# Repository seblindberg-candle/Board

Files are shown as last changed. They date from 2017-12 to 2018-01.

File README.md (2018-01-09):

# Candle Board

The EAGLE Cad board files for the Candle project can be found here.

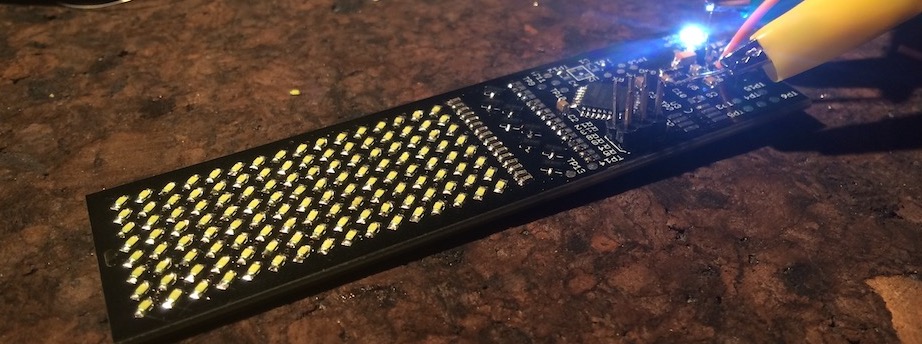
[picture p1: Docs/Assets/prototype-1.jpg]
Prototype 1


## TODO

- [x] Add a pull-up on the flash memory chip select line.
- [x] Fix the MOSFET orientation.
- [x] Fix the flash memory footprint.
- [x] Remove the hole.
- [x] Remove the microphone
- [ ] Switch out the power supply.
- [ ] Move the status LEDs to the back.
- [ ] Move the button to a more reachable position
- [ ] Make the serial port easier to connect to
- [ ] Increase the board length to 25-30 cm
- [x] Bias the display driver current sense line with the DAC
- [ ] Add one or two light sensors (front and/or back)

The following hardware changes are based on features/limitations in the peripherals that where not discovered until after the first revision.

- [ ] Connect the flash memory to `SPIC`
- [ ] Connect the display driver to `USARTD0`
- [ ] Connect `DISP_LE` to an event output (`PC4`, `PC7`, `PD4` or `PD7`)
- [ ] Connect `DISP_OE` to a compare output (`PD2`, since it is unused)
- [ ] Connect the board serial port to `USARTC0`

## Revisions

Board revisions are kept as tags in git. The board is generally tagged when the files have been sent off for manufacturing. To export a specific revision, simply run

```
$ git archive --format zip -o /path/to/rev-a.zip 4d268f
```

where the hash of the tag can be found by running `git show rev-a` for the specific tag.

## Notes

### MOSFET Pull-ups

The pull-ups are required because of the internal protection diods in the main IC. They will not allow the voltage to exceed ~3.8 V. The resistors connected to the gates thus serve to:

1. protect the gate from inrush current,
2. pull the gate high on startup and
3. set the voltage at the gate to a value above the turn-on threshold.

## Scripts

Some ruby scripts are included for generating EAGLE commands that place some of the more repetitive components. There are tools in EAGLE for achieving the same thing and they are most likely better, but a) I did not know that at the time and b) the scripts allowed be to also remove the labels, which would otherwise have been quite a task in itself. 

To run the scripts you need to locate the Scripts folder in your terminal of choice and type `ruby place-diods.rb`. Then press `enter` and copy the output into the command input in EAGLE.

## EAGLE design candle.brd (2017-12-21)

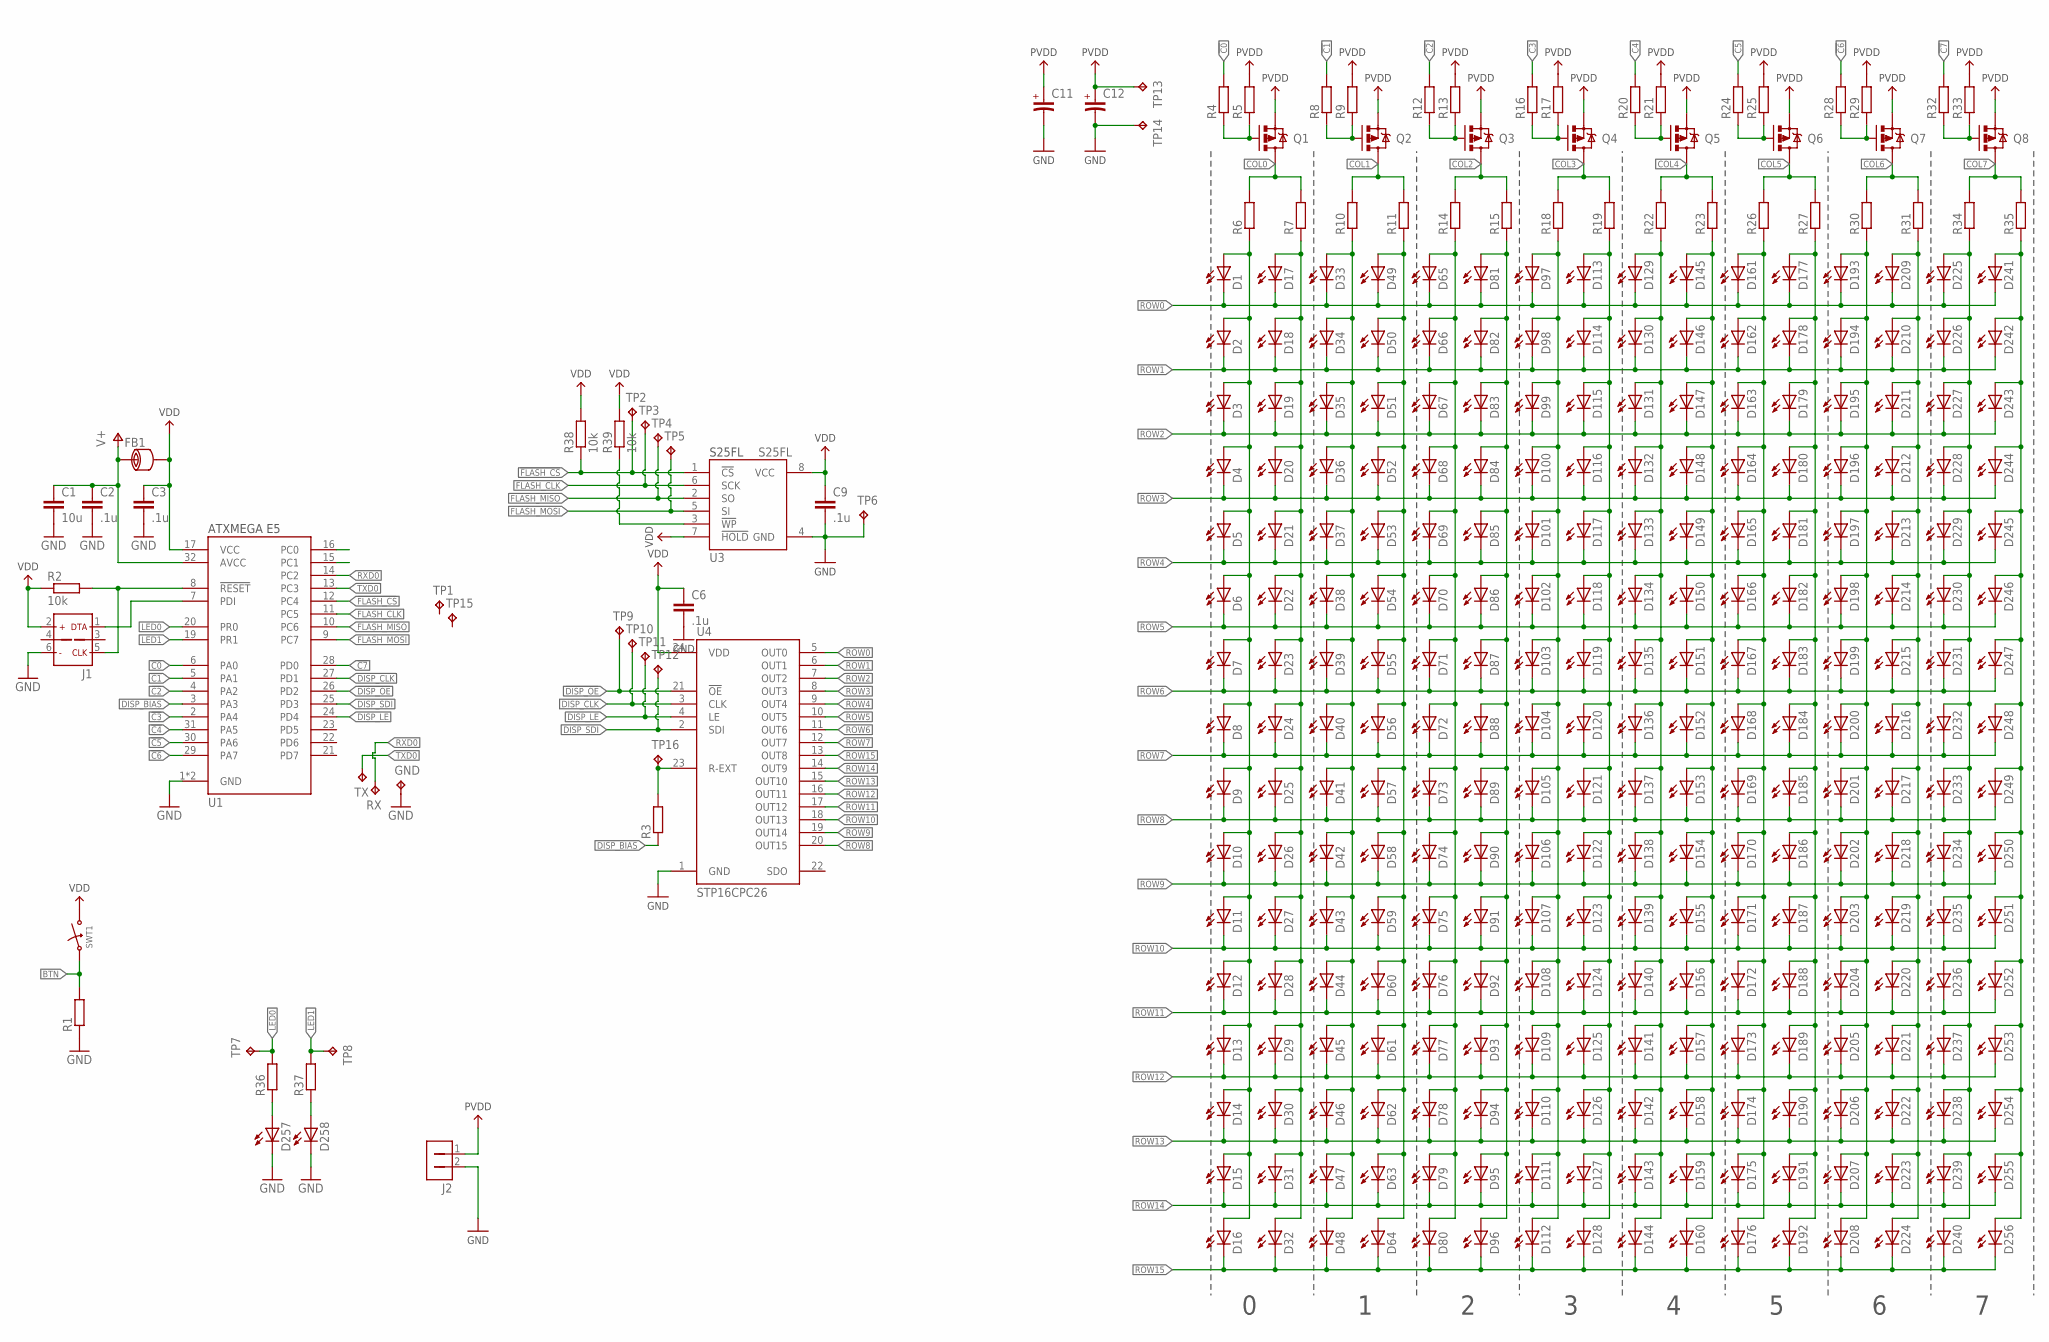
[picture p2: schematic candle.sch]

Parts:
C1: 10u; 0805
C2, C3, C6, C9: .1u; 0805
C11, C12: C_POL_1206; 1206_POL
D1, D2, D3, D4, D5, D6, D7, D8, D9, D10, D11, D12, D13, D14, D15, D16, D17, D18, D19, D20, D21, D22, D23, D24, D25, D26, D27, D28, D29, D30, D31, D32, D33, D34, D35, D36, D37, D38, D39, D40, D41, D42, D43, D44, D45, D46, D47, D48, D49, D50, D51, D52, D53, D54, D55, D56, D57, D58, D59, D60, D61, D62, D63, D64, D65, D66, D67, D68, D69, D70, D71, D72, D73, D74, D75, D76, D77, D78, D79, D80, D81, D82, D83, D84, D85, D86, D87, D88, D89, D90, D91, D92, D93, D94, D95, D96, D97, D98, D99, D100, D101, D102, D103, D104, D105, D106, D107, D108, D109, D110, D111, D112, D113, D114, D115, D116, D117, D118, D119, D120, D121, D122, D123, D124, D125, D126, D127, D128, D129, D130, D131, D132, D133, D134, D135, D136, D137, D138, D139, D140, D141, D142, D143, D144, D145, D146, D147, D148, D149, D150, D151, D152, D153, D154, D155, D156, D157, D158, D159, D160, D161, D162, D163, D164, D165, D166, D167, D168, D169, D170, D171, D172, D173, D174, D175, D176, D177, D178, D179, D180, D181, D182, D183, D184, D185, D186, D187, D188, D189, D190, D191, D192, D193, D194, D195, D196, D197, D198, D199, D200, D201, D202, D203, D204, D205, D206, D207, D208, D209, D210, D211, D212, D213, D214, D215, D216, D217, D218, D219, D220, D221, D222, D223, D224, D225, D226, D227, D228, D229, D230, D231, D232, D233, D234, D235, D236, D237, D238, D239, D240, D241, D242, D243, D244, D245, D246, D247, D248, D249, D250, D251, D252, D253, D254, D255, D256, D257, D258: LED_0805; 0805_LED
FB1: FB_0603; 0603
GND: TPB1,27; B1,27
J1: PDI_LOCK; 2X3_LOCK
J2: 1X2_MOLEX_53254
Q1, Q2, Q3, Q4, Q5, Q6, Q7, Q8: PMV160UP; SOT23
R1, R3, R4, R5, R6, R7, R8, R9, R10, R11, R12, R13, R14, R15, R16, R17, R18, R19, R20, R21, R22, R23, R24, R25, R26, R27, R28, R29, R30, R31, R32, R33, R34, R35, R36, R37: R_0603; 0603
R2: 10k; 0805
R38, R39: 10k; 0603
RX: TPB1,27; B1,27
SWT1: BUTTON_SMD_2P; BTN_SMD_2PIN
TP1, TP2, TP3, TP4, TP5, TP6, TP7, TP8, TP9, TP10, TP11, TP12, TP13, TP14, TP15, TP16: TPB1,27; B1,27
TX: TPB1,27; B1,27
U1: ATXMEGA_E5_TQFP; TQFP32
U3: S25FL; SO8
U4: STP16CPC26TSSOP24; TSSOP24

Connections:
!C0: R4.2, U1.6 (PA0)
!C0_: Q1.1 (G), R4.1, R5.1
!C1: R8.2, U1.5 (PA1)
!C2: R12.2, U1.4 (PA2)
!C3: R16.2, U1.2 (PA4)
!C3_: Q4.1 (G), R16.1, R17.1
!C4: R20.2, U1.31 (PA5)
!C5: R24.2, U1.30 (PA6)
!C5_: Q6.1 (G), R24.1, R25.1
!C6: R28.2, U1.29 (PA7)
!C6_: Q7.1 (G), R28.1, R29.1
!C7: R32.2, U1.28 (PD0)
!C7_: Q8.1 (G), R32.1, R33.1
!DISP_OE: TP9.TP, U1.26 (PD2), U4.21 (!OE)
!FLASH_CS: R38.1, TP2.TP, U1.12 (PC4), U3.1 (!CS)
!RESET: J1.5 (CLK), R2.2, U1.8 (!RESET)
BTN: R1.2, SWT1.1
COL0: Q1.3 (D), R6.2, R7.2
COL1: Q2.3 (D), R10.2, R11.2
COL2: Q3.3 (D), R14.2, R15.2
COL3: Q4.3 (D), R18.2, R19.2
COL4: Q5.3 (D), R22.2, R23.2
COL5: Q6.3 (D), R26.2, R27.2
COL6: Q7.3 (D), R30.2, R31.2
COL7: Q8.3 (D), R34.2, R35.2
DISP_BIAS: R3.1, U1.3 (PA3)
DISP_CLK: TP10.TP, U1.27 (PD1), U4.3 (CLK)
DISP_LE: TP11.TP, U1.24 (PD4), U4.4 (LE)
DISP_SDI: TP12.TP, U1.25 (PD3), U4.2 (SDI)
FLASH_CLK: TP3.TP, U1.11 (PC5), U3.6 (SCK)
FLASH_MISO: TP4.TP, U1.10 (PC6), U3.2 (SO)
FLASH_MOSI: TP5.TP, U1.9 (PC7), U3.5 (SI)
GND: C1.2, C2.2, C3.2, C6.2, C9.2, C11.2, C12.2, D257.C, D258.C, GND.TP, J1.6 (GND), J2.2, R1.1, TP6.TP, TP14.TP, U1.1 (GND), U1.18 (GND), U3.4 (GND), U4.1 (GND)
LED0: R36.2, TP7.TP, U1.20 (PR0)
LED1: R37.2, TP8.TP, U1.19 (PR1)
unnamed: D257.A, R36.1
unnamed: D1.A, D2.A, D3.A, D4.A, D5.A, D6.A, D7.A, D8.A, D9.A, D10.A, D11.A, D12.A, D13.A, D14.A, D15.A, D16.A, R6.1
unnamed: D17.A, D18.A, D19.A, D20.A, D21.A, D22.A, D23.A, D24.A, D25.A, D26.A, D27.A, D28.A, D29.A, D30.A, D31.A, D32.A, R7.1
unnamed: D258.A, R37.1
unnamed: R39.1, U3.3 (!WP)
unnamed: Q2.1 (G), R8.1, R9.1
unnamed: D65.A, D66.A, D67.A, D68.A, D69.A, D70.A, D71.A, D72.A, D73.A, D74.A, D75.A, D76.A, D77.A, D78.A, D79.A, D80.A, R14.1
unnamed: D81.A, D82.A, D83.A, D84.A, D85.A, D86.A, D87.A, D88.A, D89.A, D90.A, D91.A, D92.A, D93.A, D94.A, D95.A, D96.A, R15.1
unnamed: R3.2, TP16.TP, U4.23 (R-EXT)
unnamed: D129.A, D130.A, D131.A, D132.A, D133.A, D134.A, D135.A, D136.A, D137.A, D138.A, D139.A, D140.A, D141.A, D142.A, D143.A, D144.A, R22.1
unnamed: D145.A, D146.A, D147.A, D148.A, D149.A, D150.A, D151.A, D152.A, D153.A, D154.A, D155.A, D156.A, D157.A, D158.A, D159.A, D160.A, R23.1
unnamed: Q3.1 (G), R12.1, R13.1
unnamed: Q5.1 (G), R20.1, R21.1
unnamed: D97.A, D98.A, D99.A, D100.A, D101.A, D102.A, D103.A, D104.A, D105.A, D106.A, D107.A, D108.A, D109.A, D110.A, D111.A, D112.A, R18.1
unnamed: D113.A, D114.A, D115.A, D116.A, D117.A, D118.A, D119.A, D120.A, D121.A, D122.A, D123.A, D124.A, D125.A, D126.A, D127.A, D128.A, R19.1
unnamed: D161.A, D162.A, D163.A, D164.A, D165.A, D166.A, D167.A, D168.A, D169.A, D170.A, D171.A, D172.A, D173.A, D174.A, D175.A, D176.A, R26.1
unnamed: D177.A, D178.A, D179.A, D180.A, D181.A, D182.A, D183.A, D184.A, D185.A, D186.A, D187.A, D188.A, D189.A, D190.A, D191.A, D192.A, R27.1
unnamed: D193.A, D194.A, D195.A, D196.A, D197.A, D198.A, D199.A, D200.A, D201.A, D202.A, D203.A, D204.A, D205.A, D206.A, D207.A, D208.A, R30.1
unnamed: D209.A, D210.A, D211.A, D212.A, D213.A, D214.A, D215.A, D216.A, D217.A, D218.A, D219.A, D220.A, D221.A, D222.A, D223.A, D224.A, R31.1
unnamed: D225.A, D226.A, D227.A, D228.A, D229.A, D230.A, D231.A, D232.A, D233.A, D234.A, D235.A, D236.A, D237.A, D238.A, D239.A, D240.A, R34.1
unnamed: D241.A, D242.A, D243.A, D244.A, D245.A, D246.A, D247.A, D248.A, D249.A, D250.A, D251.A, D252.A, D253.A, D254.A, D255.A, D256.A, R35.1
unnamed: D33.A, D34.A, D35.A, D36.A, D37.A, D38.A, D39.A, D40.A, D41.A, D42.A, D43.A, D44.A, D45.A, D46.A, D47.A, D48.A, R10.1
unnamed: D49.A, D50.A, D51.A, D52.A, D53.A, D54.A, D55.A, D56.A, D57.A, D58.A, D59.A, D60.A, D61.A, D62.A, D63.A, D64.A, R11.1
PDI: J1.1 (DATA), U1.7 (PDI)
PVDD: C11.1, C12.1, J2.1, Q1.2 (S), Q2.2 (S), Q3.2 (S), Q4.2 (S), Q5.2 (S), Q6.2 (S), Q7.2 (S), Q8.2 (S), R5.2, R9.2, R13.2, R17.2, R21.2, R25.2, R29.2, R33.2, TP13.TP
ROW0: D1.C, D17.C, D33.C, D49.C, D65.C, D81.C, D97.C, D113.C, D129.C, D145.C, D161.C, D177.C, D193.C, D209.C, D225.C, D241.C, U4.5 (OUT0)
ROW1: D2.C, D18.C, D34.C, D50.C, D66.C, D82.C, D98.C, D114.C, D130.C, D146.C, D162.C, D178.C, D194.C, D210.C, D226.C, D242.C, U4.6 (OUT1)
ROW2: D3.C, D19.C, D35.C, D51.C, D67.C, D83.C, D99.C, D115.C, D131.C, D147.C, D163.C, D179.C, D195.C, D211.C, D227.C, D243.C, U4.7 (OUT2)
ROW3: D4.C, D20.C, D36.C, D52.C, D68.C, D84.C, D100.C, D116.C, D132.C, D148.C, D164.C, D180.C, D196.C, D212.C, D228.C, D244.C, U4.8 (OUT3)
ROW4: D5.C, D21.C, D37.C, D53.C, D69.C, D85.C, D101.C, D117.C, D133.C, D149.C, D165.C, D181.C, D197.C, D213.C, D229.C, D245.C, U4.9 (OUT4)
ROW5: D6.C, D22.C, D38.C, D54.C, D70.C, D86.C, D102.C, D118.C, D134.C, D150.C, D166.C, D182.C, D198.C, D214.C, D230.C, D246.C, U4.10 (OUT5)
ROW6: D7.C, D23.C, D39.C, D55.C, D71.C, D87.C, D103.C, D119.C, D135.C, D151.C, D167.C, D183.C, D199.C, D215.C, D231.C, D247.C, U4.11 (OUT6)
ROW7: D8.C, D24.C, D40.C, D56.C, D72.C, D88.C, D104.C, D120.C, D136.C, D152.C, D168.C, D184.C, D200.C, D216.C, D232.C, D248.C, U4.12 (OUT7)
ROW8: D9.C, D25.C, D41.C, D57.C, D73.C, D89.C, D105.C, D121.C, D137.C, D153.C, D169.C, D185.C, D201.C, D217.C, D233.C, D249.C, U4.20 (OUT15)
ROW9: D10.C, D26.C, D42.C, D58.C, D74.C, D90.C, D106.C, D122.C, D138.C, D154.C, D170.C, D186.C, D202.C, D218.C, D234.C, D250.C, U4.19 (OUT14)
ROW10: D11.C, D27.C, D43.C, D59.C, D75.C, D91.C, D107.C, D123.C, D139.C, D155.C, D171.C, D187.C, D203.C, D219.C, D235.C, D251.C, U4.18 (OUT13)
ROW11: D12.C, D28.C, D44.C, D60.C, D76.C, D92.C, D108.C, D124.C, D140.C, D156.C, D172.C, D188.C, D204.C, D220.C, D236.C, D252.C, U4.17 (OUT12)
ROW12: D13.C, D29.C, D45.C, D61.C, D77.C, D93.C, D109.C, D125.C, D141.C, D157.C, D173.C, D189.C, D205.C, D221.C, D237.C, D253.C, U4.16 (OUT11)
ROW13: D14.C, D30.C, D46.C, D62.C, D78.C, D94.C, D110.C, D126.C, D142.C, D158.C, D174.C, D190.C, D206.C, D222.C, D238.C, D254.C, U4.15 (OUT10)
ROW14: D15.C, D31.C, D47.C, D63.C, D79.C, D95.C, D111.C, D127.C, D143.C, D159.C, D175.C, D191.C, D207.C, D223.C, D239.C, D255.C, U4.14 (OUT9)
ROW15: D16.C, D32.C, D48.C, D64.C, D80.C, D96.C, D112.C, D128.C, D144.C, D160.C, D176.C, D192.C, D208.C, D224.C, D240.C, D256.C, U4.13 (OUT8)
RXD0: RX.TP, U1.14 (PC2)
TXD0: TX.TP, U1.13 (PC3)
V+: C1.1, C2.1, FB1.1, U1.32 (AVCC)
VDD: C3.1, C6.1, C9.1, FB1.2, J1.2 (VCC), R2.1, R38.2, R39.2, SWT1.2, U1.17 (VCC), U3.7 (!HOLD), U3.8 (VCC), U4.24 (VDD)

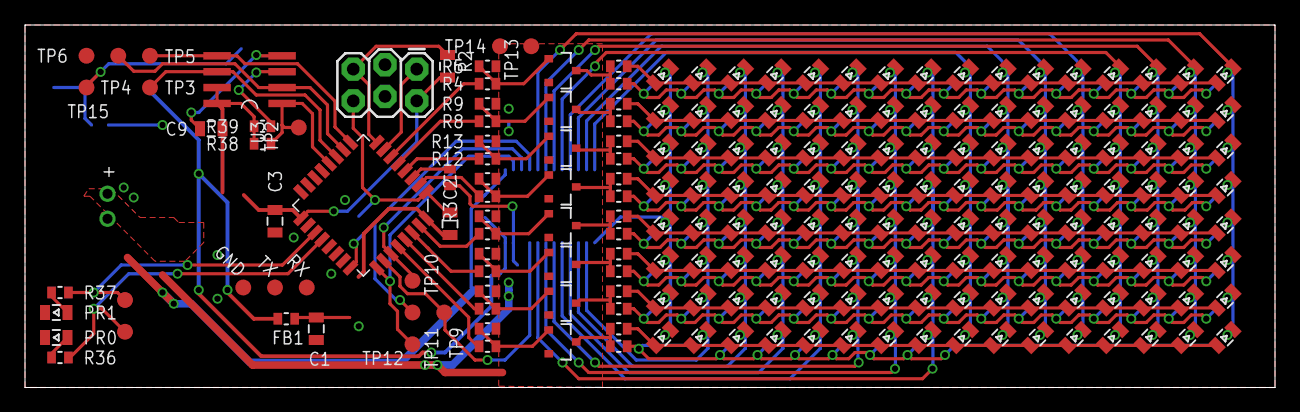
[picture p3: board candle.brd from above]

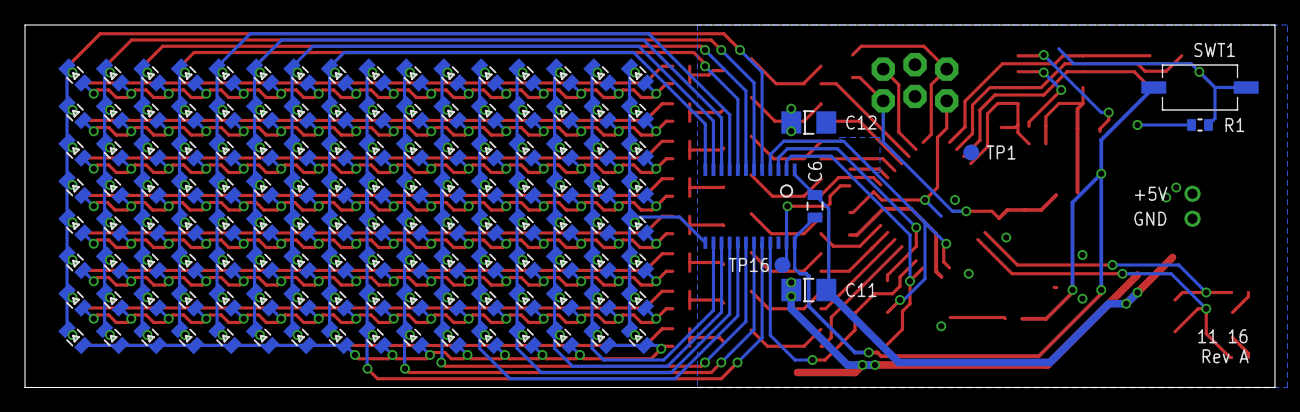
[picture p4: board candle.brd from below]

Board: 2 copper layers, 100.0 x 29.0 mm, 338 parts (137 on the bottom side), 80 nets.

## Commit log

2017-11-12 Removed microphone and some connectors
    [candle.brd, candle.sch]
2017-12-19 Fixed the transistor pinout error and updated eagle
    [candle.brd, candle.sch]
2017-12-21 Rewired the flash chip and rotated the mosfets
    [candle.brd, candle.sch]
2017-12-21 Cleaned up the flash and removed unused pins
    [candle.brd, candle.sch]
2017-12-21 Added some todos and verified the flash foodprint
    [candle.brd, candle.sch]
2018-01-09 Added an image of the first prototype
